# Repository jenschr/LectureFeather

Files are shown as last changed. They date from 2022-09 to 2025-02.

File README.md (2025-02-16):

# LectureFeather
A Feather dev board based on ESP32-S3, made for lecturing Embedded Systems (PG5501), M2M (TEK303) and Edge To App (PGR212) at Kristiania University. Feel free to use these Kicad files to make your own boards for use in your own lectures or [purchase premade boards from Maketronics](https://maketronics.no/products/lecturefeather/).

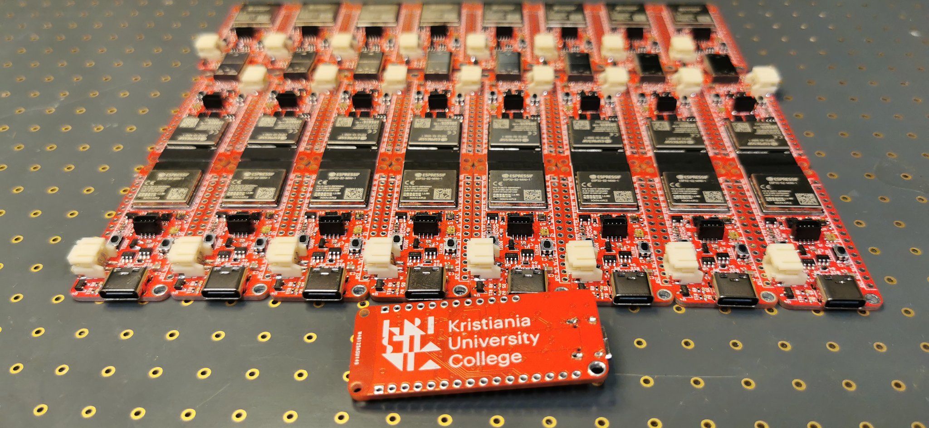
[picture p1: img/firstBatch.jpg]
First batch


## Thanks to Adafruit
This board is based on the Feather ESP32-S3 from Adafruit and while I have remade the project in Kicad, the job was so much easier thanks to all the great work and research by Adafruit. Thus I'm keeping with the [CC-BY-SA3.0 license](./license.txt) so be sure to share if you redistribute/remake.

This board will make it really easy for my students to extend the base functionality using FeatherWings and Stemma sensors from Adafruit. I highly recommend Adafruit products and they do fantastic work for the hardware commmunity.

## Usage
To use the board, set the Arduino IDE, PlatformIO or another IDE to use the board named "Adafruit ESP32-S3 Feather". This will ensure proper operation so that defines such as LED_BUILTIN and auto-programming will work. Refer to the original [Adafruit Guide](https://learn.adafruit.com/adafruit-esp32-s2-feather) for details.

As in the Adafruit design, special features are on these pins:
* I2C is on IO03 and IO04. Initiate I2C using wire.begin(3,4);
* Separate power supply for I2C devices are on IO07. Set this low before going into low power mode.
* LED_BUILTIN is on IO13

Here are some differences from the Adafruit development board:

* Light/lux sensor (LTR-329) on I2C address 0x29
* Temperature/moisture sensor (SHT31) on I2C address 0x44
* Accelerometer (LIS3DH) on I2C address 0x18
* The Hall sensor (MT8691AT) is on IO01. Larger ESP modules have this builtin, but the Mini modules do not, so I added this.
* I've also swapped the Neopixel (ws2812-type) to a Dotstar (APA102-2020). This is using IO33 for data and IO21 for clock.
* I've removed the LC709203 battery monitor as that wasn't available for months and I could not easily find a good alternative.

## Project files

## Known issues
- Version 1.0 had the Temperature sensor placed too close to the ESP32 module. This caused Temperature readins to be off by quite a bit. For Version 1.1 the sensor was moved further away, but it's still reading too high. Next version should move it all the way back to the USB connector as well as add cutouts to reduce coupling to the copper planes on the PCB.
- The board is pin compatible with both S2 and S3 MINI modules. The choice of using S3 modules in 2023 is the one I've regretted the most since tooling just isn't there for the alternate USB mode. This requires lots of custom setup to work well. I made a [writeup on solving the ESP32-S3 issues for PlatformIO](https://flashgamer.com/blog/comments/solving-platformio-issues-with-the-adafruit-feather-s3), but there are issues for Arduino as well. I've tried solving some of these with the tooling, but I'm having a hard time explaining to the maintainers what is S3 issues vs my custom board. They seem to (rightfully) think that anyone commenting on a board programming issue don't know what they're talking about, so this may take time. Use the S2 for less tooling problems is my current suggestion.
- I'm thinking on adding one more sensor in the next version of the board. I'm open to suggestions on what to add, so find my email on my blog and message me.

### PCB
The [PCB folder](./pcb) holds all the Kicad files I've used for making my boards. Please do not include any logos if you remake this board. Here you'll also find the Errata for versions of this board.

### Code
The [Example folder](./examples) holds a single .ino file that will test all the features of the board. Lots of libraries are required, so be sure to read the Include section of the file. Project file for PlatformIO used for default firmware [can be found here](https://github.com/jenschr/TestAll).

Please note that to make ESP32-S3 work painless in PlatformIO [ref](https://github.com/espressif/arduino-esp32/issues/6762#issuecomment-1182821492), we need to add the following two lines to platformio.ini:

    monitor_speed = 115200
    build_flags =   -DARDUINO_USB_MODE=1
                    -DARDUINO_USB_CDC_ON_BOOT=1
    
Note that if you use PlatformIO, I wrote up a [long article on how to solve the most common issues with the ESP32-S3 for PlatformIO on my blog](https://flashgamer.com/blog/comments/solving-platformio-issues-with-the-adafruit-feather-s3).

### BOM
The [HTML BOM](./bom) lists all the components used in the design and shows their position on the board. Great for curious students that want to know it all.

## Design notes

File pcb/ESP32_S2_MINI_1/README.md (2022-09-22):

# Dev board for lecturing Embedded & M2M

## Errata
Known bugs and limitations for this project

### Version 1.1
Yet to be produced & tested.

### Version 1.0
- APA102 used IO26 for data. This conflicts with PSRAM. Move to IO33.
- Temperature sensor is placed too close the the ESP-module, so it reads the temp of the board, not the air around it. Adafruit has a [similar problem](https://learn.adafruit.com/adafruit-esp32-s2-feather/pinouts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) with the BME280 they use in their design.
- Type-C receptacle footprint works great for industrial production, but gives 30% failure/bridges when producing locally. Reduce size of pads for next revision.
- Boot-button needs more space so it's easier to press

### Version 0.9 (not published to git)
- Swapped battery pins
- Swapped unstable BH1730 sensor

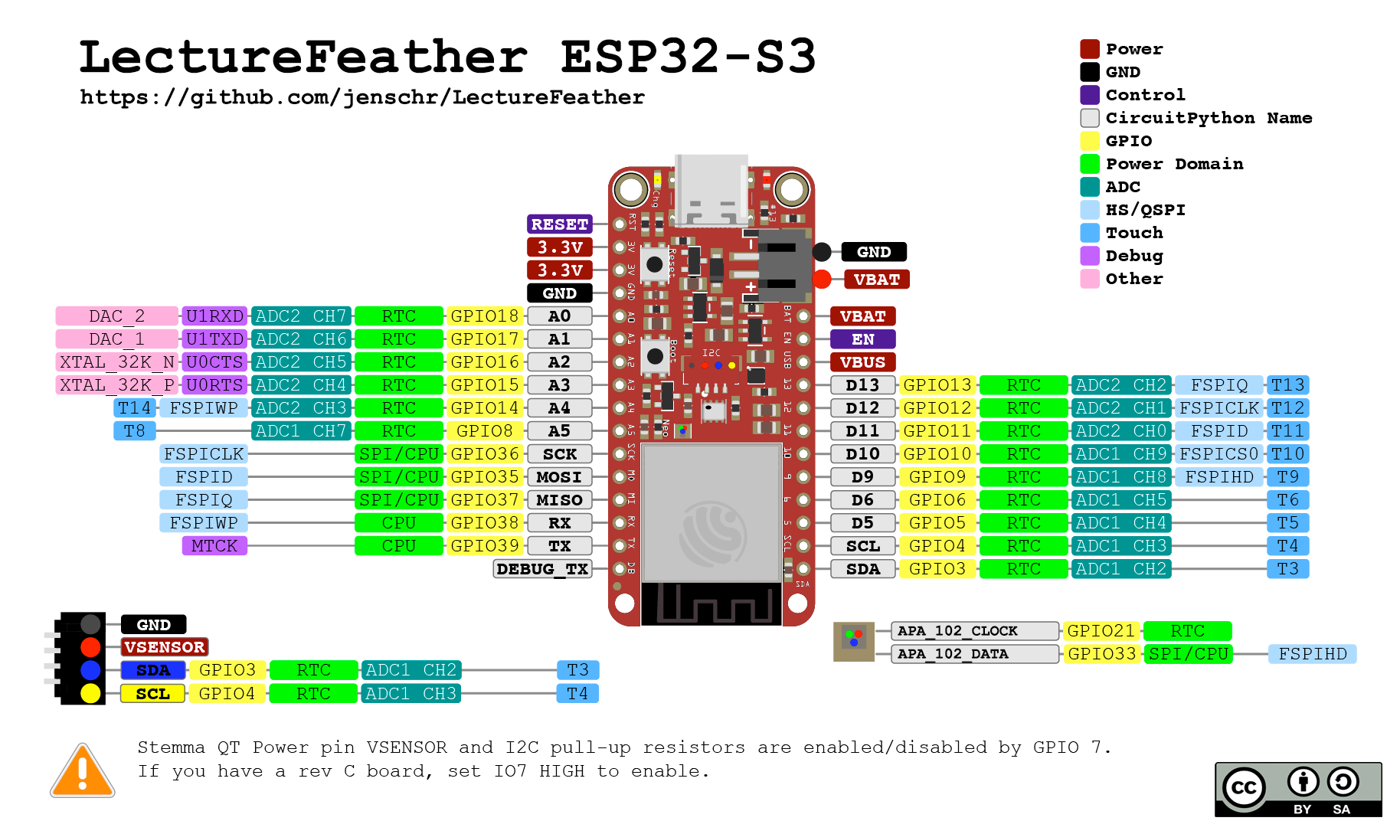
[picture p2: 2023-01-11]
img/pinout.png

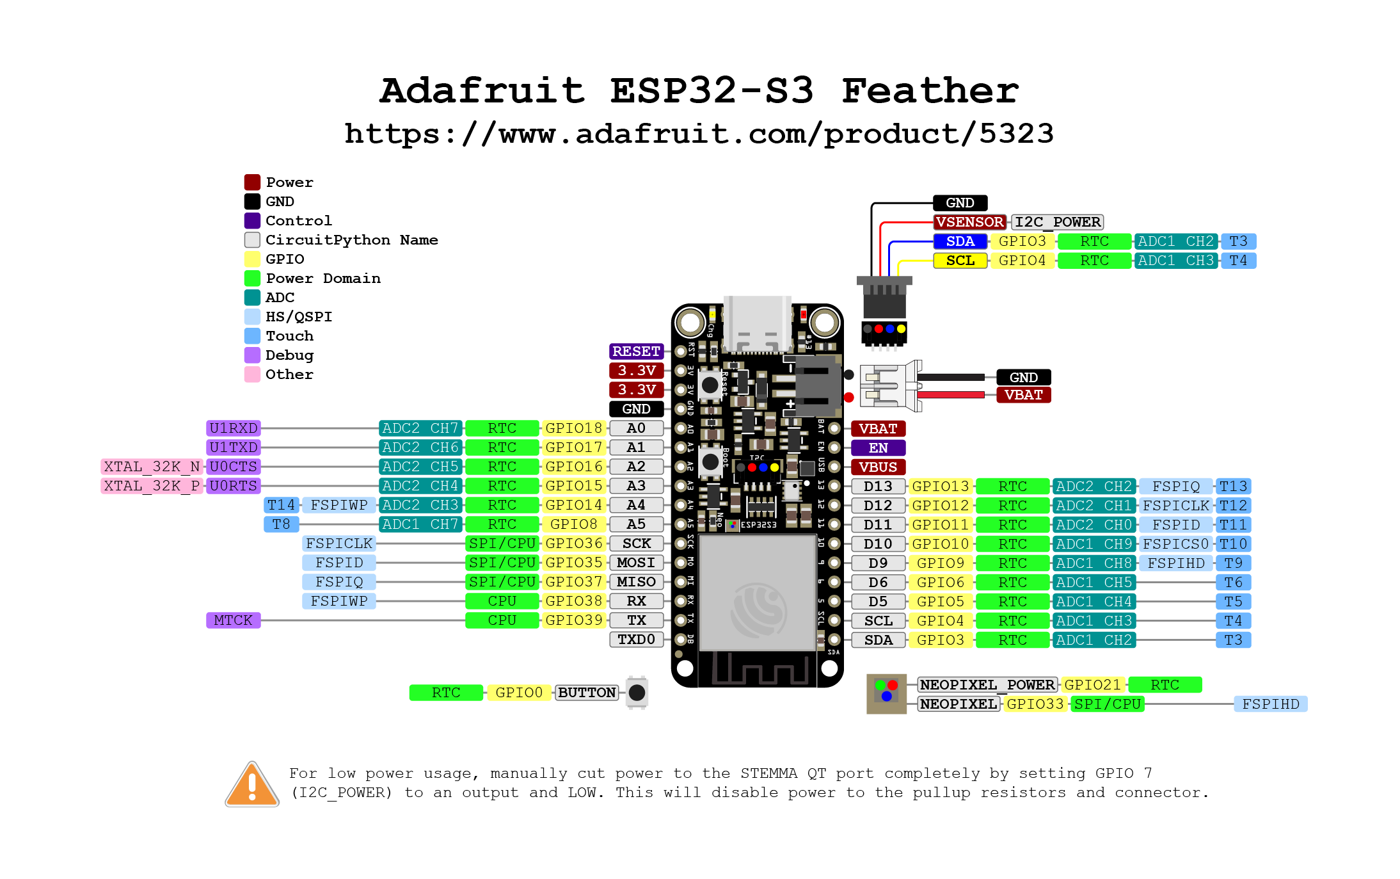
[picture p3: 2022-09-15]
pcb/ESP32_S2_MINI_1/datasheets/adafruit_products_Adafruit_Feather_ESP32-S3_Pinout.png

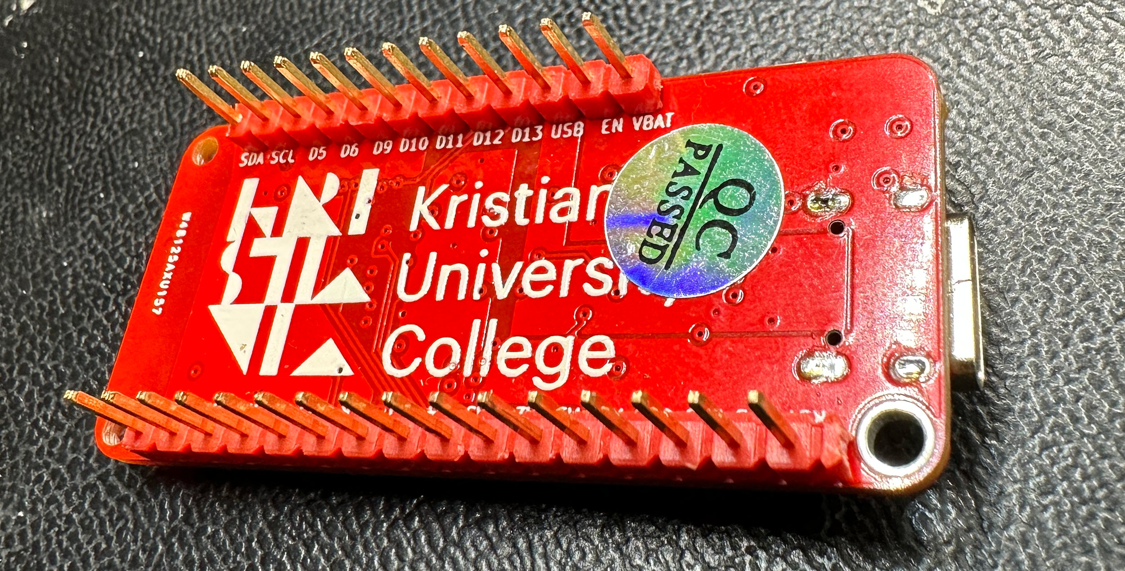
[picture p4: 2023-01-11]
img/secondbatch_bottom.jpg

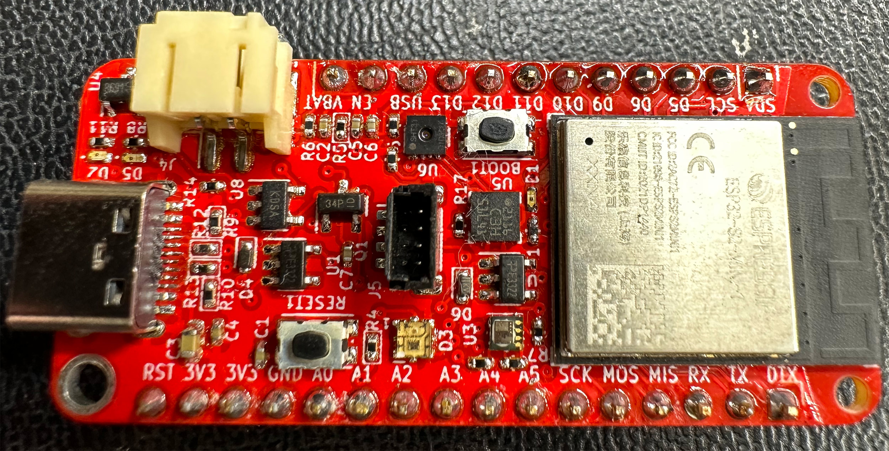
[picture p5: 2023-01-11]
img/secondbatch_top.jpg

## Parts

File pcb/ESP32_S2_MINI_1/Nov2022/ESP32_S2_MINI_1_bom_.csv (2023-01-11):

Component | Description | Part | References | Value | Footprint | Quantity Per PCB | Datasheet | MFGR | MPN
1 | Push button switch, generic, two pins | SW_Push | BOOT1 | BOOT | SW_Push_1P1T_NO_CK_KMR2 | 1 |  | C&K | KMR241GLFS
2 | Unpolarized capacitor | C | C1 C2 C4 C5 C6 C7 | 0.1uF | C_0402_1005Metric | 6 | ~ | Samsung | CL10B104KO8NFNC
3 | Unpolarized capacitor, small symbol | C_Small | C3 | 10uF | C_0603_1608Metric | 1 | ~
4 | RGB LED with integrated controller | APA102-2020 | D3 | APA102-2020 | LED-APA102-2020 | 1 | http://www.led-color.com/upload/202210/LC8822-2020-6%20EN.pdf | Shenzhen LED Color Co.,LTD | LC8822-2020-6
5 | Light emitting diode | LED | D1 D2 D5 | LED | LED_0402_1005Metric | 3 | ~
6 | Diode | D | D4 D6 | MSK4005 | D_SOD-523 | 2 | ~ | Shikues | MSK4005
7 | Generic connector, single row, 01x02, script generated (kicad-library-utils/schlib/autogen/connector/) | Conn_01x02_Female | J4 | Conn_01x02_Female | JST_PH_B2B-PH-SM4-TB_1x02-1MP_P2.00mm_Vertical | 1 | ~
8 | Generic connector, single row, 01x12, script generated (kicad-library-utils/schlib/autogen/connector/) | Conn_01x12_Female | J2 | Conn_01x12_Female | PinHeader_1x12_P2.54mm_Vertical | 1 | ~
9 | Generic connector, single row, 01x16, script generated (kicad-library-utils/schlib/autogen/connector/) | Conn_01x16_Female | J3 | Conn_01x16_Female | PinHeader_1x16_P2.54mm_Vertical | 1 | ~
10 | Generic connector, single row, 01x04, script generated (kicad-library-utils/schlib/autogen/connector/) | Conn_01x04_Female | J5 | STEMMA | JST_SH_BM04B-SRSS-TB_1x04-1MP_P1.00mm_Vertical | 1 | ~
11 | USB 2.0-only Type-C Receptacle connector | USB_C_Receptacle_USB2.0 | J1 | USB_C_Receptacle_USB2.0 | TYPE-C-31-M-12 | 1 | https://www.usb.org/sites/default/files/documents/usb_type-c.zip | Korean Hroparts Elec | TYPE-C-31-M-12
12 | -3A Id, -20V Vds, P-Channel MOSFET, SOT-23 | DMG2301L | Q1 | DMG3415u | SOT-23 | 1 | https://www.diodes.com/assets/Datasheets/DMG2301L.pdf | Diodes Incorporated | DMG3415U-7
13 | Resistor | R | R12 R13 | 33R | R_0402_1005Metric | 2 | ~
14 | Resistor | R | R1 R8 R11 | 1k | R_0402_1005Metric | 3 | ~
15 | Resistor | R | R9 R10 R14 | 5.1k | R_0402_1005Metric | 3 | ~
16 | Resistor | R | R2 R3 R4 R5 R15 R16 R17 | 10k | R_0402_1005Metric | 7 | ~ | Stackpole | RMCF0603JG10K0
17 | Resistor | R | R6 R7 | 100k | R_0402_1005Metric | 2 | ~
18 | Push button switch, generic, two pins | SW_Push | RESET1 | RESET | SW_Push_1P1T_NO_CK_KMR2 | 1 |  | C&K | KMR241GLFS
19 | 600mA low dropout linear regulator, with enable pin, 3.8V-6V input voltage range, 3.3V fixed positive output, SOT-23-5 | AP2112K-3.3 | U1 U7 | AP2112K-3.3 | SOT-23-5 | 2 | https://www.diodes.com/assets/Datasheets/AP2112.pdf | Diodes Incorporated | AP2112K-3.3TRG1
20 | ESP32-S2-MINI-1 and ESP32-S2-MINI-1U are two powerful, generic Wi-Fi MCU modules that have a rich set of peripherals. They are an ideal choice for a wide variety of application scenarios relating to Internet of Things (IoT), wearable electronics and smart home. | ESP32-S2-MINI-1 | U2 | ESP32-S3-MINI-1 | ESP32-S2-MINI-1 | 1 | https://www.espressif.com/sites/default/files/documentation/esp32-s2-mini-1_esp32-s2-mini-1u_datasheet_en.pdf | Espressif Systems | ESP32-S3-MINI-1-N8
21 | 3-Axis Accelerometer, 2/4/8/16g range, I2C/SPI interface, LGA-16 | LIS3DH | U5 | LIS3DH | LGA-16_3x3mm_P0.5mm_LayoutBorder3x5y | 1 | https://www.st.com/resource/en/datasheet/cd00274221.pdf | ST | LIS3DH
22 | ambient light sensor, i2c interface, 0.01 to 64k lux, 2.4-3.6V | LTR-329ALS-01 | U3 | LTR-329ALS-01 | LTR-329ALS-01 | 1 | https://no.mouser.com/datasheet/2/239/liteon_LTR-329ALS-01-1175539.pdf | Lite-On | LTR-329ALS-01
23 | Single cell, Li-Ion/Li-Po charge management controller, 4.20V, Tri-State Status Output, in SOT23-5 package | MCP73831-2-OT | U8 | MCP73831-2-OT | SOT-23-5 | 1 | http://ww1.microchip.com/downloads/en/DeviceDoc/20001984g.pdf | Microchip Technology | MCP73831T-4ADI/OT
24 | Hall Effect Switch, SOT-23 | SM351LT | U4 | MT8691AT | SOT-23 | 1 | https://sensing.honeywell.com/honeywell-sensing-nanopower-series-product-sheet-50095501-a-en.pdf | Honeywell | MT8691AT
25 | I²C humidity and temperature sensor, ±2%RH, ±0.2°C, DFN-8 | SHT31-DIS | U6 | SHT31-DIS | Sensirion_DFN-8-1EP_2.5x2.5mm_P0.5mm_EP1.1x1.7mm | 1 | https://www.sensirion.com/fileadmin/user_upload/customers/sensirion/Dokumente/2_Humidity_Sensors/Datasheets/Sensirion_Humidity_Sensors_SHT3x_Datasheet_digital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 | Sensiron | SHT31-DIS
Component Groups: | 25
Component Count: | 46
Fitted Components: | 46
Number of PCBs: | 1
Total components: | 46
Schematic Version:
Schematic Date:
PCB Variant: | default
BoM Date: | 2022 November 23, Wednesday 21:07:22
Schematic Source: | ESP32_S2_MINI_1.kicad_sch
KiCad Version: | Eeschema (6.0.4-0)

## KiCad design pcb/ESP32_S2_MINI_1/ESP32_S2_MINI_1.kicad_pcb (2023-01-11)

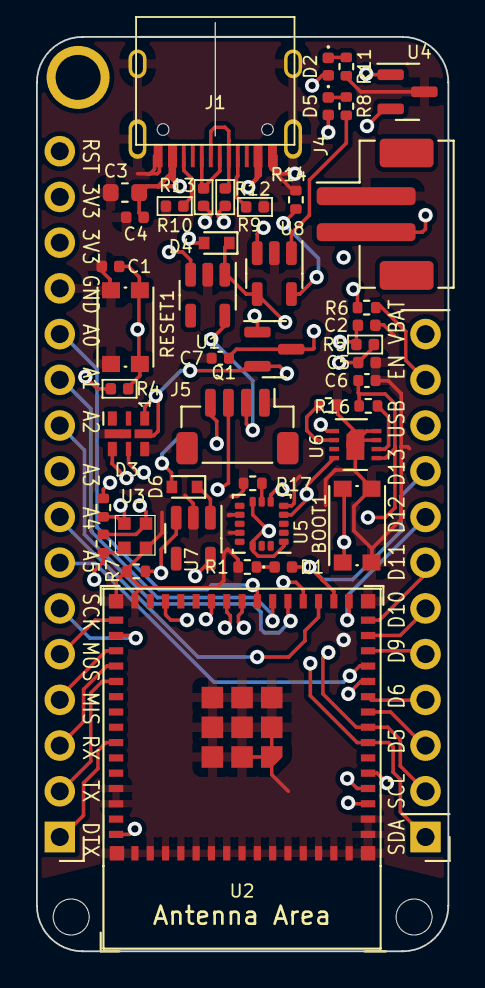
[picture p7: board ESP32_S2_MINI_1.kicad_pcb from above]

Board: 4 copper layers, 22.9 x 50.8 mm, 50 parts (1 on the bottom side), 49 nets.

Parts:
BOOT1: BOOT; SW_Push_1P1T_NO_CK_KMR2
C1, C2, C4, C5, C6, C7: 0.1uF; C_0402_1005Metric
C3: 10uF; C_0603_1608Metric
D1, D2, D5: LED; LED_0402_1005Metric
D3: APA102-2020; LED-APA102-2020
D4, D6: MSK4005; D_SOD-523
H1: MountingHole; MountingHole_2.5mm_Pad
H2, H3: MountingHole; MountingHole_2.0mm_NoPad
H4: HK Logo; HK_engelsk-logo
J1: USB_C_Receptacle_USB2.0; TYPE-C-31-M-12
J2: Conn_01x12_Female; PinHeader_1x12_P2.54mm_Vertical
J3: Conn_01x16_Female; PinHeader_1x16_P2.54mm_Vertical
J4: Conn_01x02_Female; JST_PH_B2B-PH-SM4-TB_1x02-1MP_P2.00mm_Vertical
J5: STEMMA; JST_SH_BM04B-SRSS-TB_1x04-1MP_P1.00mm_Vertical
Q1: DMG3415u; SOT-23
R1, R8, R11: 1k; R_0402_1005Metric
R2, R3, R4, R5, R15, R16, R17: 10k; R_0402_1005Metric
R6, R7: 100k; R_0402_1005Metric
R9, R10, R14: 5.1k; R_0402_1005Metric
R12, R13: 33R; R_0402_1005Metric
RESET1: RESET; SW_Push_1P1T_NO_CK_KMR2
U1, U7: AP2112K-3.3; SOT-23-5
U2: ESP32-S3-MINI-1; ESP32-S2-MINI-1
U3: LTR-329ALS-01
U4: MT8691AT; SOT-23
U5: LIS3DH; LGA-16_3x3mm_P0.5mm_LayoutBorder3x5y
U6: SHT31-DIS; Sensirion_DFN-8-1EP_2.5x2.5mm_P0.5mm_EP1.1x1.7mm
U8: MCP73831-2-OT; SOT-23-5

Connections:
+3.3VA: C6.1, R2.2, R3.2, R16.1, U3.1 (VDD), U5.1 (VDD_IO), U5.8 (CS), U5.14 (VDD), U6.5 (VDD), U7.5 (VOUT)
+3V3: C5.1, D2.2 (A), J3.14, J3.15, J5.2, R4.2, R5.2, U1.5 (VOUT), U2.3 (3V3), U4.1 (VCC)
/APA_CLOCK: D3.5 (CKI), U2.25 (GPIO21)
/APA_DATA: D3.4 (SDI), U2.28 (GPIO33)
/BOOT: BOOT1.1, C2.1, R5.1, U2.4 (GPIO0/BOOT)
/DN: J1.A7 (D-), J1.B7 (D-), R12.1
/DP: J1.A6 (D+), J1.B6 (D+), R13.1
/ENABLE: C1.1, R4.1, RESET1.1, U2.45 (CHIP/PU/RESET)
/USB_DN: R12.2, U2.23 (USB_D-/ADC2_CH8/GPIO19)
/USB_DP: R13.2, U2.24 (USB_D+/ADC2_CH9/GPIO20)
/VB: D3.1 (VDD), D4.1 (K), D5.2 (A), Q1.2 (S), R6.2, U1.1 (VIN), U8.4 (VDD)
A0: J3.12, U2.22 (ADC2_CH6/DAC_1/GPIO18)
A1: J3.11, U2.21 (ADC2_CH7/DAC_2/GPIO17)
A2: J3.10, U2.20 (GPIO16/ADC2_CH5/XTAL_32K_N)
A3: J3.9, U2.19 (GPIO15/ADC2_CH4/XTAL_32K_P)
A4: J3.8, U2.18 (GPIO14/ADC2_CH3)
A5: J3.7, U2.12 (GPIO8/ADC1_CH7)
D5: J2.3, U2.9 (GPIO5/ADC1_CH4)
D6: J2.4, U2.10 (GPIO6/ADC1_CH5)
D9: J2.5, U2.13 (GPIO9/ADC1_CH8)
D10: J2.6, U2.14 (GPIO10/ADC1_CH9)
D11: J2.7, U2.15 (GPIO11/ADC2_CH0)
D12: J2.8, U2.16 (GPIO12/ADC2_CH1)
D13: D1.2 (A), J2.9, U2.17 (GPIO13/ADC2_CH2)
DEBUG_TX: J3.1, U2.39 (GPIO43/U0TXD/PROG)
EN: J2.11, R6.1, U1.3 (EN)
GND: BOOT1.2, C1.2, C2.2, C3.2, C4.2, C5.2, C6.2, C7.2, D3.6 (GND), J1.A1 (GND), J1.A12 (GND), J1.B1 (GND), J1.B12 (GND), J1.S1 (SHIELD), J3.13, J4.1, J5.1, R1.1, R7.1, R9.2, R10.2, R11.1, R14.1, R15.1, R17.1, RESET1.2, U1.2 (GND), U2.1 (GND), U2.2 (GND), U2.30 (GND), U2.42 (GND), U2.43 (GND), U2.46 (GND), U3.2 (GND), U4.3 (GND), U5.5 (GND), U5.10 (GND), U5.12 (GND), U6.7 (R), U6.8 (VSS), U6.9 (VSS), U7.2 (GND), U8.2 (VSS)
I2C_PWR: R7.2, U2.11 (GPIO7/ADC1_CH6), U7.3 (EN)
I2C_SCL: J2.2, J5.4, R2.1, U2.8 (GPIO4/ADC1_CH3), U3.4 (SCL), U5.4 (SCL/SPC), U6.4 (SCL)
I2C_SDA: J2.1, J5.3, R3.1, U2.7 (GPIO3/ADC1_CH2), U3.3 (SDA), U5.6 (SDA/SDI/SDO), U6.1 (SDA)
MAG: U2.5 (GPIO1/ADC1_CH0), U4.2 (OUTPUT)
MISO: J3.4, U2.33 (GPIO37)
MOSI: J3.5, U2.31 (GPIO35)
unnamed: D1.1 (K), R1.2
unnamed: D2.1 (K), R11.2
unnamed: D5.1 (K), R8.2
unnamed: D6.1 (K), U7.1 (VIN)
unnamed: J1.A5 (CC1), R9.1
unnamed: J1.B5 (CC2), R10.1
unnamed: R8.1, U8.1 (STAT)
unnamed: R14.2, U8.5 (PROG)
unnamed: R15.2, U6.2 (ADDR)
unnamed: R16.2, U6.6 (~RESET)
unnamed: R17.2, U5.7 (SDO/SA0)
RX: J3.3, U2.34 (GPIO38)
SCK: J3.6, U2.32 (GPIO36)
TX: J3.2, U2.35 (MTCK/JTAG/GPIO39)
USB: C3.1, C4.1, D4.2 (A), D6.2 (A), J1.A4 (VBUS), J1.A9 (VBUS), J1.B4 (VBUS), J1.B9 (VBUS), J2.10, Q1.1 (G)
VBAT: C7.1, J2.12, J4.2, Q1.3 (D), U8.3 (VBAT)

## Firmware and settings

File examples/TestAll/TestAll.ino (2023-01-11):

#include <Arduino.h>
#include <Wire.h>
#include <i2cdetect.h>
#include <Adafruit_LIS3DH.h>
#include <Adafruit_Sensor.h>
#include <Adafruit_DotStar.h>
#include "Adafruit_SHT31.h"
#include "Adafruit_LTR329_LTR303.h"

// There is only one pixel on the board
#define NUMPIXELS 1

#define DATAPIN    33
#define CLOCKPIN   21
 
Adafruit_DotStar strip(NUMPIXELS, DATAPIN, CLOCKPIN, DOTSTAR_BRG);

Adafruit_LTR329 ltr = Adafruit_LTR329();
Adafruit_SHT31 sht31 = Adafruit_SHT31();
Adafruit_LIS3DH lis = Adafruit_LIS3DH();

long firstPixelHue = 0;
int counter = 0;

void rainbow(); // predeclare method we'll use later

void setup() {
  Serial.begin(9600);
  Wire.begin(3, 4);
  delay(1500);
  Serial.println("ready?");
  delay(1500);

  if (! lis.begin(0x18)) {
    Serial.println("Couldn't find LIS3DH sensor!");
    while (1) yield();
  }
  Serial.println("Found LIS3DH sensor!");

  if (! sht31.begin(0x44)) {
    Serial.println("Couldn't find SHT31 sensor!");
    while (1) delay(1);
  }
  Serial.println("Found SHT31 sensor!");

  if ( ! ltr.begin() ) {
    Serial.println("Couldn't find LTR sensor!");
    while (1) delay(10);
  }
  
  // Setul LTR sensor (see advanced demo for all options!
  Serial.println("Found LTR sensor!");
  ltr.setGain(LTR3XX_GAIN_4);
  ltr.setIntegrationTime(LTR3XX_INTEGTIME_50);
  ltr.setMeasurementRate(LTR3XX_MEASRATE_50);

  strip.begin();            // Initialize LED pins for output
  strip.setBrightness(20);  // Avoid blinding yourself
  strip.show();             // Turn all LEDs off ASAP

  i2cdetect();

  pinMode(LED_BUILTIN, OUTPUT);
}

void loop() {
  // RGB led
  rainbow();

  // Only update sensors every now and then
  if( counter%50==0 ) 
  {
    //Blink builtin LED
    digitalWrite( LED_BUILTIN, !digitalRead(13) );
    
    // Temp & humid
    float t = sht31.readTemperature();
    float h = sht31.readHumidity();
  
    if (! isnan(t)) {  // check if 'is not a number'
      Serial.print("Temp *C = "); Serial.print(t);
    } else {
      Serial.println("Failed to read temperature");
    }
  
    if (! isnan(h)) {  // check if 'is not a number'
      Serial.print("\tHum. % = "); Serial.print(h);
    } else {
      Serial.println("Failed to read humidity");
    }
  
    // Light
    uint16_t visible_plus_ir, infrared;
    if (ltr.newDataAvailable()) {
      bool valid = ltr.readBothChannels(visible_plus_ir, infrared);
      if (valid) {
        Serial.print("\tCH0 Visible + IR: ");
        Serial.print(visible_plus_ir);
        Serial.print("\tCH1 Infrared: ");
        Serial.print(infrared);
      }
    }

    // Accel
    lis.read();      // get X Y and Z data at once
    Serial.print("\tX:  "); Serial.print(lis.x);
    Serial.print("\tY:  "); Serial.print(lis.y);
    Serial.print("\tZ:  "); Serial.print(lis.z);
  
    Serial.println("");
  }
  else
  {
    // Just wait a little so the LED have time to update
    delay(3);
  }
  
  counter++;
}

void rainbow() {
  strip.setPixelColor(0, strip.gamma32(strip.ColorHSV(firstPixelHue)));
  strip.show(); // Update strip with new contents
  firstPixelHue += 32;
  if ( firstPixelHue > 5 * 65536 ) { firstPixelHue = 0; }
}

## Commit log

2022-09-15 First public version
    [ESP32_S2_MINI_1.kicad_pcb, ESP32_S2_MINI_1.kicad_sch]
2022-09-22 Version 1.1, see Errata for fixes
    [ESP32_S2_MINI_1-B_Cu.gbr, ESP32_S2_MINI_1-B_Mask.gbr, ESP32_S2_MINI_1-B_Paste.gbr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]
2022-11-16 Updated pin number for v1.2 of the board
2023-01-11 S3 version
    [ESP32_S2_MINI_1-B_Cu.gbr, ESP32_S2_MINI_1-B_Mask.gbr, ESP32_S2_MINI_1-B_Paste.gbr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]
